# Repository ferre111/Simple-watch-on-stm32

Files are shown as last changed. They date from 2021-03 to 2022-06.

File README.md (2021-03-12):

# Simple smartwatch on STM32

The purpose of this project is to create a smartwatch equipped with an OLED display and a set of sensors. The fundamental hardware part of this watch will be a STM32F103 microcontroller based on one the Cortex-M3 core.

Device will be capable of measuring:
- time,
- temperature,
- air pressure,
- altitude,
- magnetic field,
- acceleration

Data from sensors and current time will be displayed on the OLED display equipped with the SSD1306 driver. All sensors and display are driven by I2C interface.

List of sensors:
- MPU6050 (GY-87)
- BMP180 (GY-87)
- QMC5883L (GY-87)

A video that showing how the watch works:
https://www.youtube.com/watch?v=Y_Tc-Hr1YcA

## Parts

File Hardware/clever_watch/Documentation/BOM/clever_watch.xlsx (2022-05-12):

MPN | Comment | Designator | Footprint | Quantity
GRM155R60J475ME87D | 4.7 uF | C1, C4 | C0402 | 2
GRM155R61A105KE15J | 1 uF | C2, C3, C13, C14 | C0402 | 4
CL05A104KP5NNNC | 100 nF | C5, C6, C9, C10, C11, C15, C16, C17, C18, C19, C20, C23 | C0402 | 12
CL05B224KO5NNNC | 220 nF | C7 | C0402 | 1
GRM155R60J475ME87D | 4.7 uF | C8 | C0603 | 1
CC0402KRX7R9BB222 | 2.2 nF | C12 | C0402 | 1
CC0402JRNPO9BN100 | 10 pF | C21, C22 | C0402 | 2
ESD3Z5V0 | 5 V | D1, D2 | SOD-323FL_477AB_ONS | 2
1PS70SB85.115 | D_DOUBLE_CK2 | D3 | SOT65P210X110-3N | 1
OLED-SSD1306 | OLED Display | DS1 | OLED SSD1306 | 1
MCP73831T-2ACI/OT | MCP73831T | IC1 | SOT-23-5_MC_MCH | 1
LP2981IM5-3.3/NOPB | LP2981IM5 | IC2 | SOT-23-5_MC_MCH | 1
HMC5883L | HMC5883L | IC3 | LPCC16_HNW | 1
STM32F103C8T6 | STM32F103CxT | IC4 | LQFP48-7x7mm | 1
MPU6050 | MPU6050 | IC5 | QFN24_4X4X0P9_IVS | 1
BMP180 | BMP180 | IC6 | BMP180 | 1
10118194-0001LF | micro USB | J1 | AMPHENOL_10118194-0001LF | 1
 | JUMPER_3_PADS | JP1, JP2, JP3, JP4 | 0402 jumper x3 | 4
RF-BUB190TS-CA | Blue | LED1 | LED_0603 | 1
LD-EDPE-1209 | BUZZER | LS1 | HDR_1X2_MALE | 1
ZL315-4SGH | 1x4 Header | P1 | CONN_15-91-2045_MOL | 1
BC847B-TP | Q_NPN_BEC | Q1 | SOT-23 | 1
 | Val | R1 | R0402 | 1
RC0402FR-0710KL | 10k | R2, R4, R5, R6, R8, R14, R15, R16, R17, R20, R21, R22 | R0402 | 12
RC0402FR-07470R | 470 | R3, R7 | R0402 | 2
AC0402FR-07470KL | 470K | R9, R10, R11, R12, R23, R24 | R0402 | 6
[NoValue], RC0402FR-07100RL | 100 | R13, R18, R19 | R0402 | 3
KMS221G LFS | tact switch | SW1 | KMS221GLFS | 1
ABS07-32.768KHZ-7-T | 32768 Hz | XTAL1 | ABS0732768KHZ7T | 1

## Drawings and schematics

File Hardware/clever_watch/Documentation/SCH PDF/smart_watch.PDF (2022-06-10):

3 2 1

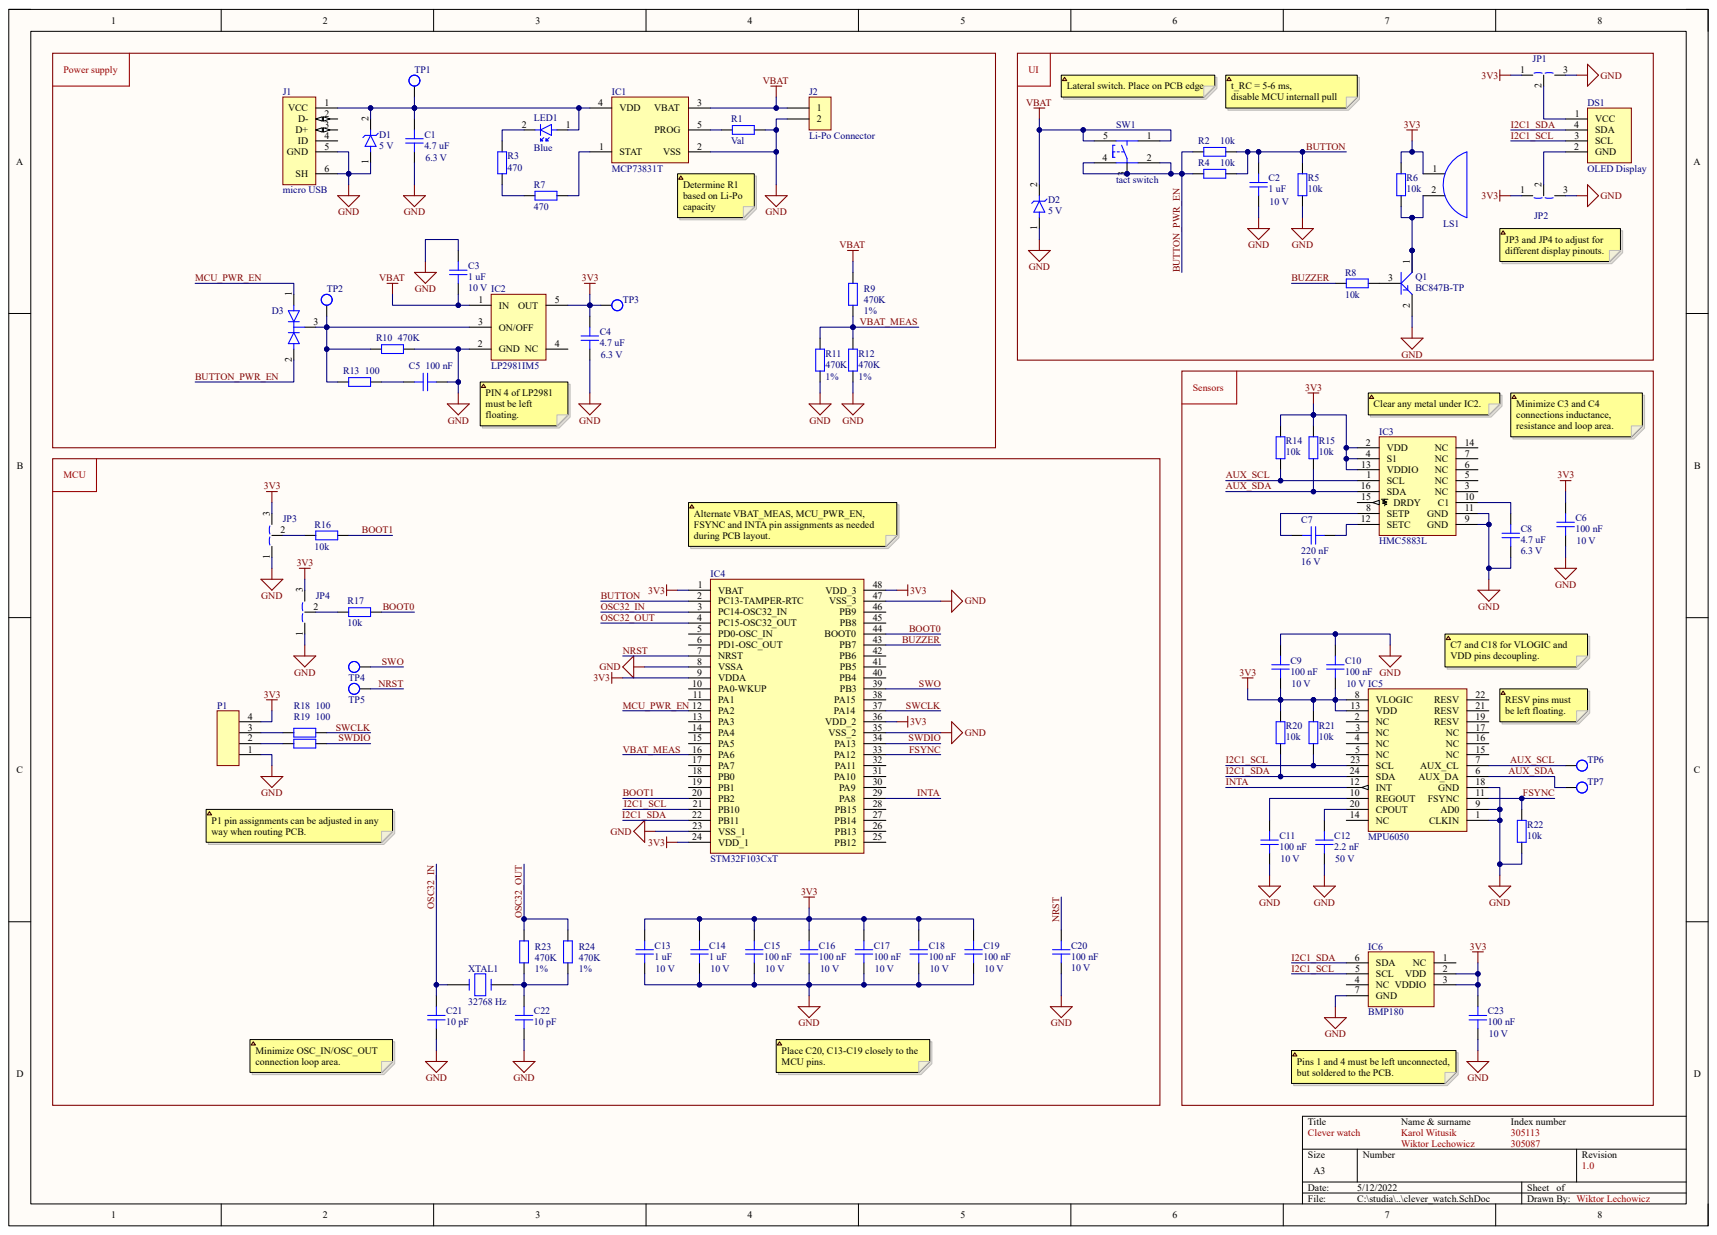
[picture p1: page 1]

Lateral switch. Place on PCB edge.

disable MCU internall pull

Determine R1
based on Li-Po
capacity

JP3 and JP4 to adjust for
different display pinouts.

Clear any metal under IC2.

Minimize C3 and C4
connections inductance,
resistance and loop area.

Alternate VBAT_MEAS, MCU_PWR_EN,
FSYNC and INTA pin assignments as needed
during PCB layout.

C7 and C18 for VLOGIC and
VDD pins decoupling.

P1 pin assignments can be adjusted in any
way when routing PCB.

Place C20, C13-C19 closely to the
MCU pins.

Pins 1 and 4 must be left unconnected,
but soldered to the PCB.

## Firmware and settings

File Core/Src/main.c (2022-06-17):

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
/* Includes ------------------------------------------------------------------*/
#include "main.h"
#include "adc.h"
#include "i2c.h"
#include "rtc.h"
#include "tim.h"
#include "gpio.h"

/* USER CODE BEGIN Includes */
#include "MPU6050.h"
#include "pressure_sensor.h"
#include "OLED.h"
#include <stdio.h>
#include "menu.h"
#include "button.h"
#include "battery_managment.h"
/* USER CODE END Includes */


/* USER CODE BEGIN PV */
/*Structure for initialization MPU6050.*/
struct MPU6050_ctx MPU6050 =
{
    .sample_rate_div        = 255,
    .dlpf_acc_bandwidth     = MPU6050_BANDWIDTH_260,
    .gyro_full_scale_range  = MPU6050_GYRO_FULL_SCALE_1000,
    .acc_full_scale_range   = MPU6050_ACC_FULL_SCALE_2,
    .fifo_data_enable_mask  = MPU6050_ACCEL_FIFO_EN | MPU6050_ZG_FIFO_EN | MPU6050_YG_FIFO_EN | MPU6050_XG_FIFO_EN | MPU6050_TEMP_FIFO_EN | MPU6050_SLV0_FIFO_EN,
    .clock_select           = MPU6050_PLL_X_GYRO,

    .master.master_clock_speed = MPU6050_I2C_CLOCK_SPEED_400,
    .master.mult_mst_en        = false,
    .master.wait_for_es        = true,
    .master.mst_p_nsr          = true,
    .master.slave_delay        = 0,
    .i2c_bypass_en             = false,

    .slave[0].addr      = QMC588L_ADDR,
    .slave[0].RW        = true,
    .slave[0].reg_addr  = QMC588L_XOUT_L,
    .slave[0].byte_swap = false,
    .slave[0].reg_dis   = false,
    .slave[0].group     = false,
    .slave[0].len       = 6,
    .slave[0].en        = true,

    .int_pin.level = true,
    .int_pin.open = false,
    .int_pin.latch_en = false,
    .int_pin.rd_clear = false,
    .fsync_int_level = false,
    .fsync_int_en = false,
    .i2c_bypass_en = false,

    .interrupt_en_mask = MPU6050_INT_DATA_RDY_EN | MPU6050_INT_FIFO_OFLOW_EN | MPU6050_INT_MST_EN,
    .fifo_en    = true,
    .i2c_mst_en = true,

    .QMC5883L_ctx.mode = QMC5883L_MODE_CONTINUOUS,
    .QMC5883L_ctx.output_data_rate = QMC5883L_ODR_10,
    .QMC5883L_ctx.full_scale = QMC5883L_RNG_8G,
    .QMC5883L_ctx.over_sample_ratio = QMC5883L_OSR_512
};
/* USER CODE END PV */

void SystemClock_Config(void);
/**
  * @brief  The application entry point.
  * @retval int
  */

int main(void)
{
  /* MCU Configuration--------------------------------------------------------*/

  /* Reset of all peripherals, Initializes the Flash interface and the Systick. */
  HAL_Init();

  /* Configure the system clock */
  SystemClock_Config();

  /* Initialize all configured peripherals */
  MX_GPIO_Init();
  MX_I2C2_Init();
  MX_ADC1_Init();
  MX_RTC_Init();
  MX_TIM4_Init();
  /* USER CODE BEGIN 2 */
  MPU6050_deinit();
  HAL_Delay(50);
  pressure_sensor_set_sensor_mode(PRESSURE_SENSOR_ULTRA_HIGH_RESOLUTION);
  pressure_sensor_read_calib_data();

  MPU6050_init(&MPU6050);

  OLED_Init();
  OLED_setDisplayOn();
  menu_process_init();
  HAL_ADC_Start_IT(&hadc1);
  battery_managment_voltage_stabilizer_turn_on();
//  HAL_TIM_Base_Start_IT(&htim4);
  /* USER CODE END 2 */

  /* Infinite loop */
  /* USER CODE BEGIN WHILE */
  while (1)
  {
//    QMC5883L_process();
    menu_process();
    button_process();
    OLED_update();
    HAL_Delay(50);
    /* USER CODE END WHILE */

    /* USER CODE BEGIN 3 */
  }
  /* USER CODE END 3 */
}

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
/* USER CODE BEGIN 4 */

void main_goto_stop_mode(void)
{
	OLED_setDisplayOff();
	MPU6050_deinit();
	HAL_Delay(50);
	MPU6050_sleep();
	HAL_SuspendTick();
	HAL_PWR_EnterSTOPMode(PWR_LOWPOWERREGULATOR_ON, PWR_SLEEPENTRY_WFI);
}

void main_goto_normal_mode(void)
{
	HAL_Init();
	SystemClock_Config();
	OLED_setDisplayOn();
	MPU6050_init(&MPU6050);
}


void HAL_TIM_PeriodElapsedCallback(TIM_HandleTypeDef* htim)
{
    HAL_GPIO_TogglePin(BUZZER_GPIO_Port, BUZZER_Pin);
}
/* USER CODE END 4 */
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


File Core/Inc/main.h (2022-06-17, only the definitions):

#define BUTTON_Pin GPIO_PIN_13
#define BUTTON_GPIO_Port GPIOC
#define BUTTON_EXTI_IRQn EXTI15_10_IRQn
#define MCU_PWR_EN_Pin GPIO_PIN_2
#define MCU_PWR_EN_GPIO_Port GPIOA
#define VBAT_MEAS_Pin GPIO_PIN_6
#define VBAT_MEAS_GPIO_Port GPIOA
#define INTA_Pin GPIO_PIN_8
#define INTA_GPIO_Port GPIOA
#define INTA_EXTI_IRQn EXTI9_5_IRQn
#define FSYNC_Pin GPIO_PIN_12
#define FSYNC_GPIO_Port GPIOA
#define BUZZER_Pin GPIO_PIN_7
#define BUZZER_GPIO_Port GPIOB

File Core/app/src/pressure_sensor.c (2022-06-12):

/*
 * pressure_sensor.c
 *
 *  Created on: Nov 24, 2020
 *      Author: Karol Witusik
 */

#include "pressure_sensor.h"

#define ADDR PRESSUURE_SENSOR_ADDR
#define COUNT_OF_CALIB_REG 11

#define I2C_HANDLE hi2c2

#define OUT_XLSB    0xF8
#define OUT_LSB     0xF7
#define OUT_MSB     0xF6
#define CTRL_MEAS   0xF4
#define SOFT_RESET  0xE0
#define ID          0xD0
#define CALIB0      0xAA

#define PRESS_I2C_TIMEOUT 100

//----------------------------------------------------------------------

/** @brief      Structure for calibration data.*/
struct calib_data
{
    int16_t AC1;
    int16_t AC2;
    int16_t AC3;
    uint16_t AC4;
    uint16_t AC5;
    uint16_t AC6;
    int16_t B1;
    int16_t B2;
    int16_t MB;
    int16_t MC;
    int16_t MD;
};

//----------------------------------------------------------------------

/** @brief      Structure for calculation.*/
struct calc_data
{
    int32_t     X1;
    int32_t     X2;
    int32_t     X3;
    int32_t     B3;
    uint32_t    B4;
    int32_t     B5;
    int32_t     B6;
    uint32_t    B7;
};

//----------------------------------------------------------------------

/** @brief      Structure for temperature after reading from sensor and after calculation.*/
struct temp
{
    int32_t uncomp_temp;
    int32_t true_temp;
};

//----------------------------------------------------------------------

/** @brief      Main structure.*/
struct pressure_sensor
{
    struct calib_data                   calib_data;
    struct calc_data                    calc_data;
    struct temp                         temp;
    int32_t                             uncomp_pres;
    int32_t                             true_pres;

    enum pressure_sensor_mode    mode;
};

//----------------------------------------------------------------------

static struct pressure_sensor ctx;

static uint8_t aux_tab[3];

//----------------------------------------------------------------------

static void read_uncomp_temp(void);
static void read_uncomp_pres(void);
static void calc_true_temp(void);
static void calc_true_pres(void);

//----------------------------------------------------------------------

void pressure_sensor_read_calib_data(void)
{
    /*Reading of calibration data*/
    for(uint8_t i = 0; i < COUNT_OF_CALIB_REG; i++)
    {
    	HAL_I2C_Mem_Read(&I2C_HANDLE, ADDR, CALIB0 + i * 2, 1, aux_tab, 2, PRESS_I2C_TIMEOUT);
//        myI2C_readByteStream(I2C_HANDLE, ADDR, CALIB0 + i * 2, aux_tab, 2);
        *(&ctx.calib_data.AC1 + i) = (aux_tab[0] << 8) + aux_tab[1];
    }
}

//----------------------------------------------------------------------

void pressure_sensor_set_sensor_mode(enum pressure_sensor_mode sensor_mode)
{
    ctx.mode = sensor_mode;
}

//----------------------------------------------------------------------

void pressure_sensor_read_temp_and_pres(void)
{
    read_uncomp_temp();
    read_uncomp_pres();
    calc_true_temp();
    calc_true_pres();
}

//----------------------------------------------------------------------

void pressure_sensor_get_temp(int32_t *temp)
{
    *temp = ctx.temp.true_temp;
}

//----------------------------------------------------------------------

void pressure_sensor_get_pres(int32_t *pres)
{
    *pres = ctx.true_pres;
}

//----------------------------------------------------------------------

void pressure_sensor_calc_dif_alt(int32_t initial_pres, int32_t actual_pres, float *alt)
{
    /*Formula from reference manual of BMP180 sensor.*/
    *alt = 44330 * (1 - pow((float)actual_pres/(float)initial_pres, 0.190294f));
}

//----------------------------------------------------------------------
// Static functions
//----------------------------------------------------------------------

static void read_uncomp_temp(void)
{
    /*Write proper value to measurement control register*/
    aux_tab[0] = 0x2E;
    HAL_I2C_Mem_Write(&I2C_HANDLE, ADDR, CTRL_MEAS, 1, aux_tab, 1, PRESS_I2C_TIMEOUT);
//    myI2C_writeByteStream(I2C_HANDLE, ADDR, CTRL_MEAS, aux_tab, 1);
    HAL_Delay(5);

    HAL_I2C_Mem_Read(&I2C_HANDLE, ADDR, OUT_MSB, 1, aux_tab, 2, PRESS_I2C_TIMEOUT);
//    myI2C_readByteStream(I2C_HANDLE, ADDR, OUT_MSB, aux_tab, 2);

    ctx.temp.uncomp_temp = (aux_tab[0] << 8) + aux_tab[1];
}

//----------------------------------------------------------------------

static void read_uncomp_pres(void)
{
    /*Write proper value to measurement control register*/
    aux_tab[0] = 0x34 + (ctx.mode << 6);
    HAL_I2C_Mem_Write(&I2C_HANDLE, ADDR, CTRL_MEAS, 1, aux_tab, 1, PRESS_I2C_TIMEOUT);
//    myI2C_writeByteStream(I2C_HANDLE, ADDR, CTRL_MEAS, aux_tab, 1);

    /*Choose correct delay.*/
    switch(ctx.mode)
    {
    case PRESSURE_SENSOR_ULTRA_LOW_POWER:
        HAL_Delay(5);
        break;
    case PRESSURE_SENSOR_STANDARD:
        HAL_Delay(8);
        break;
    case PRESSURE_SENSOR_HIGH_RESOLUTION:
        HAL_Delay(14);
        break;
    case PRESSURE_SENSOR_ULTRA_HIGH_RESOLUTION:
        HAL_Delay(26);
        break;
    default:
        break;
    }

    HAL_I2C_Mem_Read(&I2C_HANDLE, ADDR, OUT_MSB, 1, aux_tab, 3, PRESS_I2C_TIMEOUT);
//    myI2C_readByteStream(I2C_HANDLE, ADDR, OUT_MSB, aux_tab, 3);

    ctx.uncomp_pres = ((aux_tab[0] << 16) + (aux_tab[1] << 8) + aux_tab[2]) >> (8 - ctx.mode);
}

//----------------------------------------------------------------------

static void calc_true_temp(void)
{
    /*Formula from reference manual of BMP180 sensor.*/
    ctx.calc_data.X1 = (ctx.temp.uncomp_temp - ctx.calib_data.AC6) * ctx.calib_data.AC5 / 32768;
    ctx.calc_data.X2 = (ctx.calib_data.MC * 2048) / (ctx.calc_data.X1 + ctx.calib_data.MD);
    ctx.calc_data.B5 = ctx.calc_data.X1 + ctx.calc_data.X2;

    ctx.temp.true_temp = (ctx.calc_data.B5 + 8 ) / 16;
}

//----------------------------------------------------------------------
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

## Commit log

2020-11-30 Initial commit of OLED driver module. Functions for display initialization, drawing lines and writing a character sequences on display have been implemented.
2020-11-30 remove error codes, added function to calculate differential attitude in pressure_sensor module, in main added simple program to demonstrated data from sensor on display
    [TM2.ioc, main.c, pressure_sensor.c]
2020-12-11 Second display buffer for driving the display using DMA has been included
2021-01-09 OLED lib modified to use DMA and double buffering of display.
2021-01-09 Hal based I2C implementation has been replaced with first version of CMSIS based I2C implementation.
    [OLED.c, main.c, myI2C.c]
2021-01-10 working FIFO with acc, temp, GYRO_CONFIG magn still doesnt work
2021-01-10 Bare metal I2C with DMA implementation for I2C2 done.
2021-01-11 I2C driver updated with byte stream reading. Example usage shown in pressure_sensor.c file
2021-01-11 I2C frequency update
2021-01-12 all sensors work, improve code to display measurements
2021-01-12 sensors with i2c implementatios test part 1
2021-01-13 Writing buffers to OLED through I2C modified because of errors occurring while using another display models.
    [OLED.c, main.c, myI2C.c]
2021-01-14 code prototype for changing pages associated with data from gyroscope
2021-01-16 added spirit level page, altitude page, magnetometer page
2021-01-18 update spirit level page, added library for button
2021-01-18 Printing modification in pages to keep image more stable
2021-01-20 Revert "Merge branch 'WL_branch' into master"
    This reverts commit a6c442175a98a7e7a0b6c5428650c36e5e678102, reversing
    changes made to 4e27b8d025277ae41e2b2abd265f5a4ed318f2ab.
    [MPU6050.c, MPU6050.h, OLED.c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]
2021-01-21 added comments, change .ioc file for project solder on prototype PCB
2022-04-23 CW-10 Initial commit. Add file structure for hardware related files.
    [clever_watch.PcbDoc, clever_watch.PcbLib, clever_watch.PrjPcb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]
2022-04-23 CW-10 Add BMP180, C, C_POLARISED, HMC5883L, MPU6050, OLED, R, STM32F103CxT and TACT-SW schematic symbols.
    [clever_watch.PrjPcb, clever_watch.SchDoc, clever_watch.SchLib]
2022-04-23 Add USB_MICRO and MCP73831T-xxxx/OT symbols.
    [clever_watch.SchLib]
2022-04-23 Add power supply block schematic
    [clever_watch.PrjPcb, clever_watch.SchDoc, clever_watch.SchLib]
2022-04-23 CW-10 Add MCU section schematic.
    [clever_watch.SchDoc, clever_watch.SchLib]
2022-04-23 CW-10 Add sensors and button to schematic.
    [clever_watch.PrjPcb, clever_watch.SchDoc, clever_watch.SchLib]
2022-04-23 CW-10 Resize schematic to A3 and reorganize symbols positions. Add mounting holes.
    [clever_watch.PrjPcb, clever_watch.SchDoc, clever_watch.SchLib]
2022-04-23 CW-10 Update according to review.
    [clever_watch.PrjPcb, clever_watch.SchDoc, clever_watch.SchLib]
2022-04-27 Added components footprints
    [clever_watch.PcbLib, clever_watch.SchDoc, clever_watch.SchLib]
2022-04-27 CW-24: corrected 3pads jumper
    [clever_watch.PcbLib, clever_watch.SchLib]
2022-04-27 CW-24: added dot to 3pads jumper footprint
    [clever_watch.PcbLib, clever_watch.SchDoc, clever_watch.SchLib]
2022-04-27 added buzzer
    [clever_watch.SchDoc]
2022-04-27 updated elements footprints without reseting other parameters
    [clever_watch.SchDoc]
2022-04-27 CW-24 Add hotfixes: increase status led resistor, add piezoelectric driver, move nreset and swo signals to testpoints.
    [clever_watch.SchDoc, clever_watch.SchLib]
2022-04-27 added missing footprints and testpoints
    [clever_watch.PcbLib, clever_watch.PrjPcb, clever_watch.SchDoc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]
2022-05-12 CW-22: deployed elements, update .ioc file
    [clever_watch.PcbDoc, clever_watch.PcbLib, clever_watch.PrjPcb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]
2022-05-12 CW-22: First version of the board
    [clever_watch.PcbDoc, clever_watch.PcbLib, clever_watch.PrjPcb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]
2022-05-12 added battery plus mark
    [clever_watch.PcbDoc]
2022-05-12 CW-22: updated .ioc file, arranged resistors in series to make Wiktorek happy
    [clever_watch.PcbDoc, clever_watch.PrjPcb, clever_watch.SchDoc]
2022-05-12 CW-22: PCB corrections in accordance to review
    [clever_watch.PcbDoc, clever_watch.PcbLib, clever_watch.SchDoc]
2022-05-12 CW-22: Corrected button footprint
    [clever_watch.PcbDoc, clever_watch.PcbLib]
2022-05-12 CW-22: Swaped internal layers, added positioning holes, added gerber files and the rest of the documentation
    [clever_watch.GBL, clever_watch.GBO, clever_watch.GBP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]
2022-05-12 Add final gerber file set
2022-05-12 added necessary information about the authors to .SchDoc file
    [clever_watch.SchDoc]
2022-06-10 code ported to new PCB board
2022-06-11 Working button
2022-06-12 device sleep mode has been added
2022-06-17 added battery voltage measurment, padlock and battery icons

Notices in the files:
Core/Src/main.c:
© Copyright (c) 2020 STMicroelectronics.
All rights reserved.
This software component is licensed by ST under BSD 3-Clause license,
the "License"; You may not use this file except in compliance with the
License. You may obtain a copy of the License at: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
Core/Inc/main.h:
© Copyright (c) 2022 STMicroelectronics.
